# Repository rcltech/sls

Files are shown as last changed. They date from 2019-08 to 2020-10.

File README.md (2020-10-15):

# RC Tech Club Smart Laundry System

This is a mono-repo for the smart laundry system in RC Lee Hall

#### Directory structure

- `ec2`: The AWS EC2 service for the analytics for SLS.
- `hardware`: Code on the ESP8266
- `lambda`: Serverless functions running on the AWS Lambda, communicate with the hardware via internet.
- `sls`: The code for the website.
- `solidworks`: 3D designs for the casing of the sensor modules.

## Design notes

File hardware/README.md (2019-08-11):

# Version 3 Wifi Connection to Wifi.HK via HKU

Test machine: ESP8266

## Setup Instructions

1. Run `pip install -r requirements.txt`
2. Upload `boot.py`, `main.py` and `urequests_mod.py` to the ESP8266
3. Press the reset button to reload the scripts
4. Make sure the sensor circuit is there to read data. Otherwise, value will be 0.

### Watch it send data!

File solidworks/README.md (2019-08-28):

# Solidworks

We 3D-printed, and installed hardware on our laundry machines.

### Instructions
1. Use Solidworks 2018 to open your desired part that is stored in the `Parts/` folder.

2. Save the part as `.STL`.

3. Use Cura or any other 3D-printer software to create `.gcode` file.

4. Print with corresponding 3D printer.

### Our Results
#### Button and LED
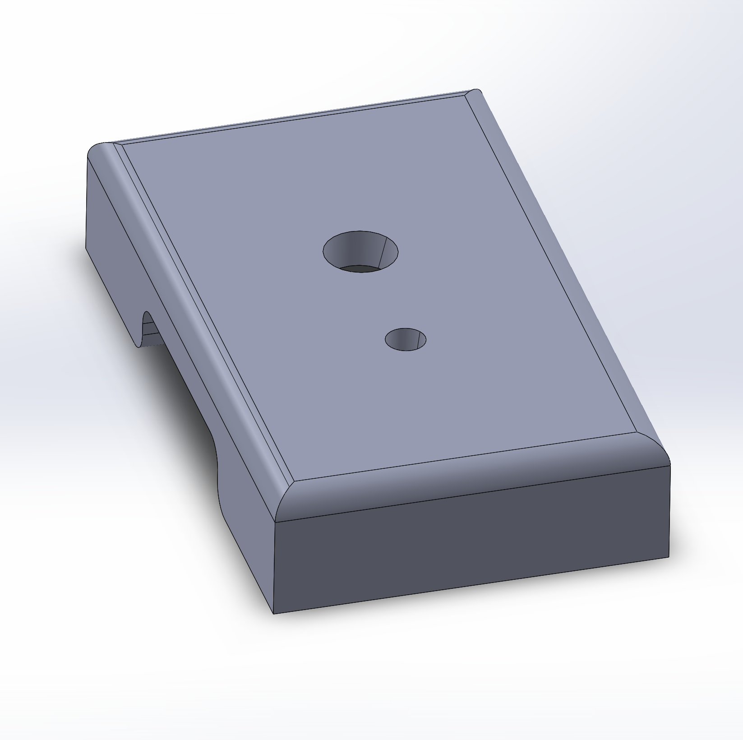
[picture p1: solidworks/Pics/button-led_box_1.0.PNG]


We made our first prototype using a button and an led. For reasons yet unknown, the micropython ESP module was unstable, and it somehow received signals from the buttons without anyone pressing them. Hence, the module kept sending false data to our firebase database, making the entire system very unstable, and unusable.

#### Light sensor
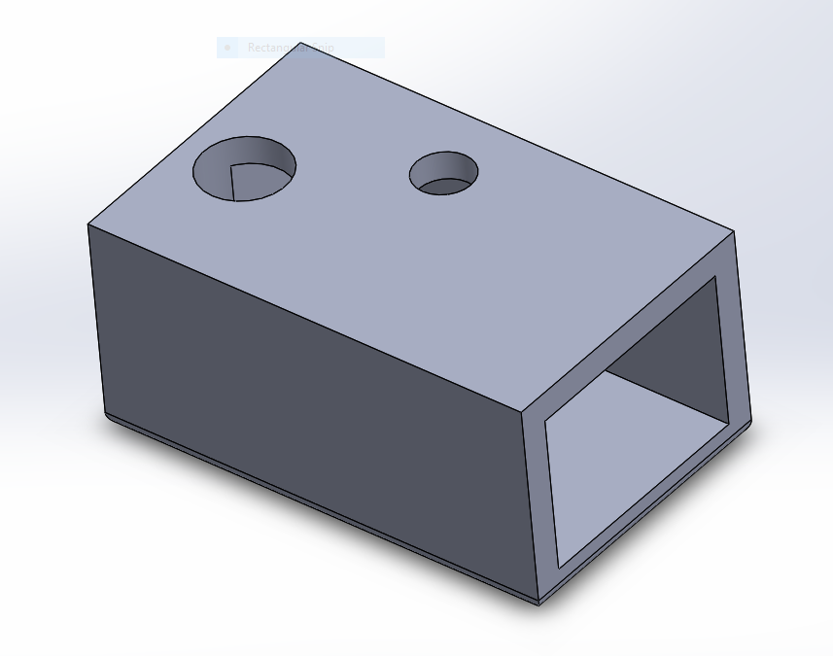
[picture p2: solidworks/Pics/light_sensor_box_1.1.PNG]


Our 2nd prototype implements a digital light sensor that would send on / off signals to the ESP module. As long as we correctly tuned the sensitivity of the sensors, they worked perfectly; so far, we have yet observe any system-disruptive fluctuations.

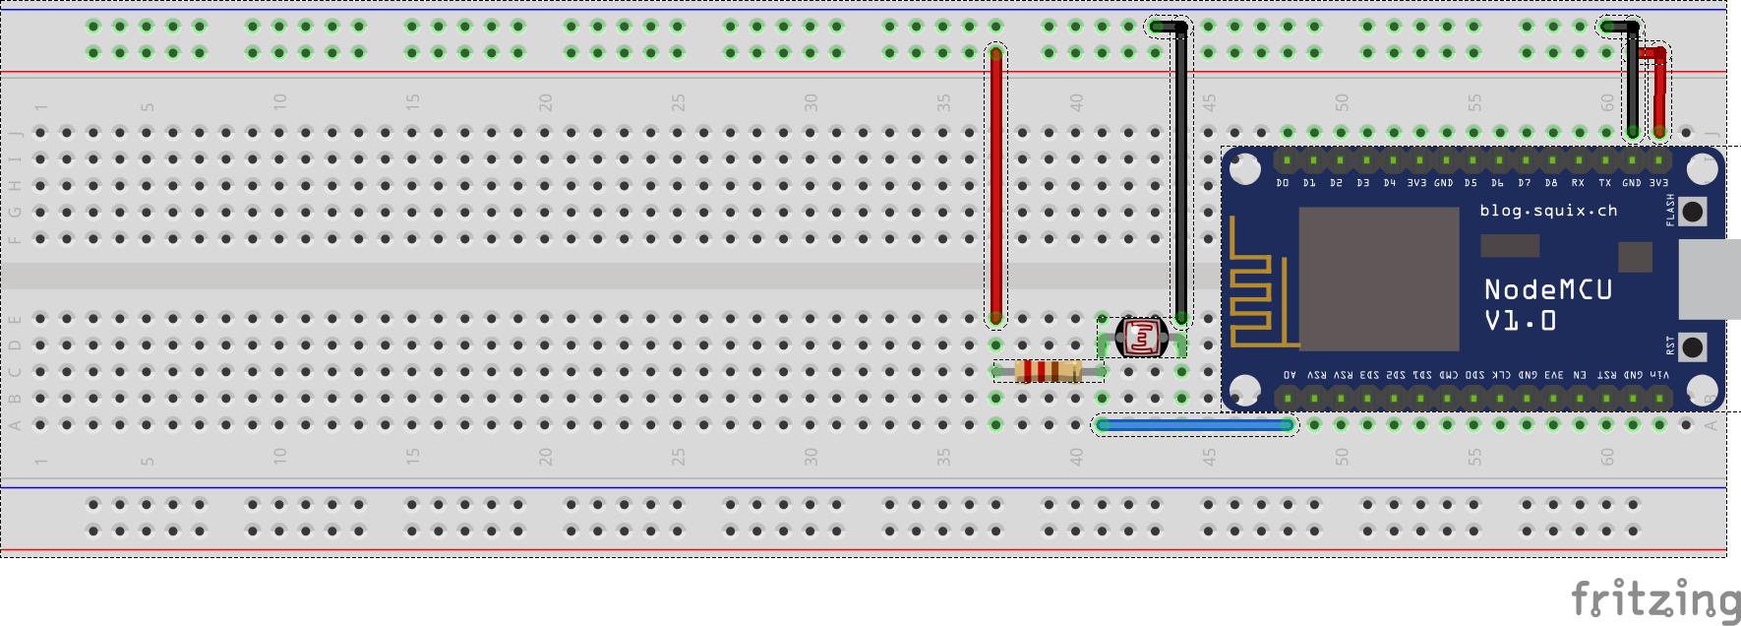
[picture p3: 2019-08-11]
hardware/sls_bb.png

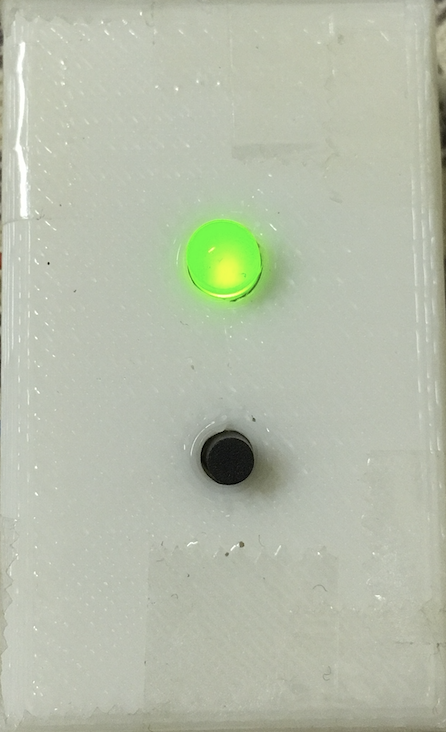
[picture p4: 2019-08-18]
sls/src/images/LED_on.png

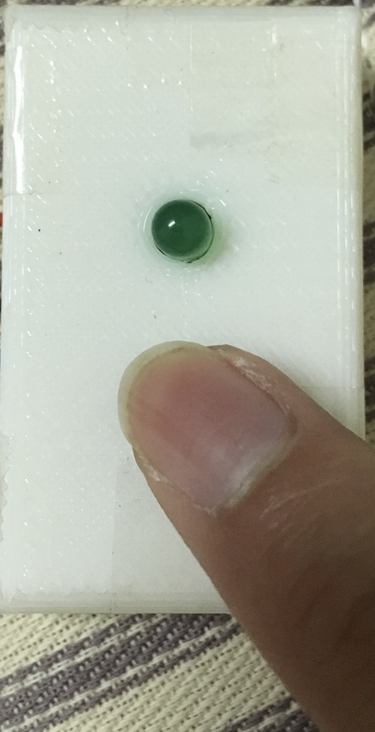
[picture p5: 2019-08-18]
sls/src/images/LED_off_pressed.png

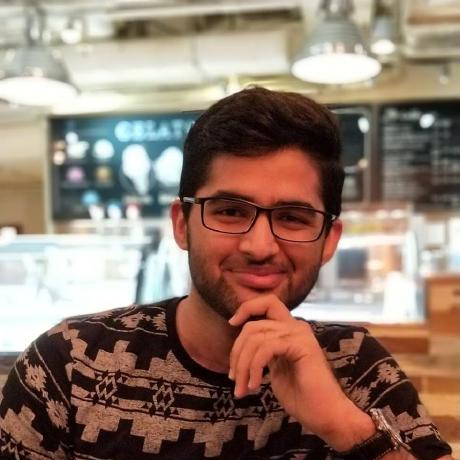
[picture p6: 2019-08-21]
sls/src/images/team-members/waqas.png

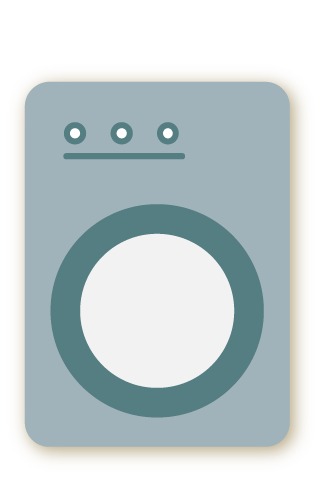
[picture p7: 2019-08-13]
sls/src/images/base.png

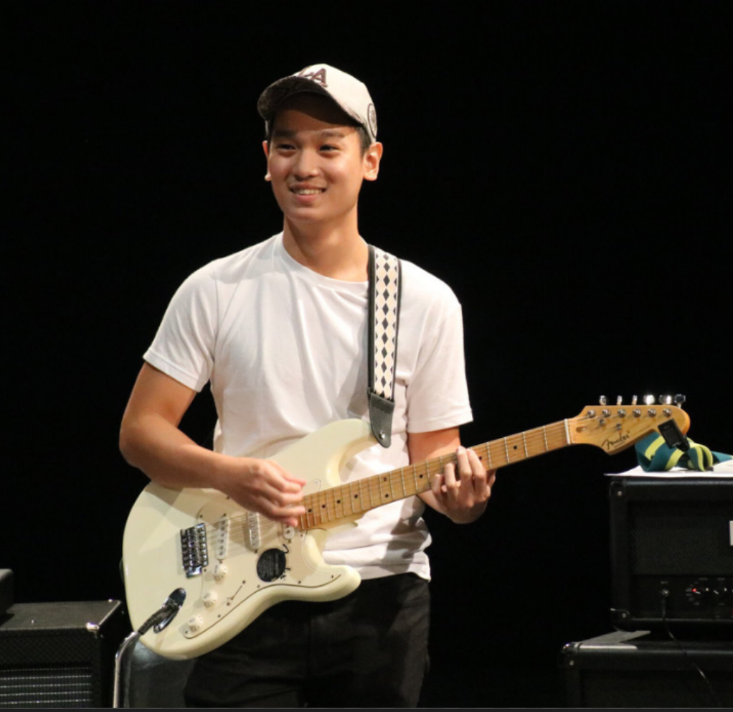
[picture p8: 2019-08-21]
sls/src/images/team-members/welvin.png

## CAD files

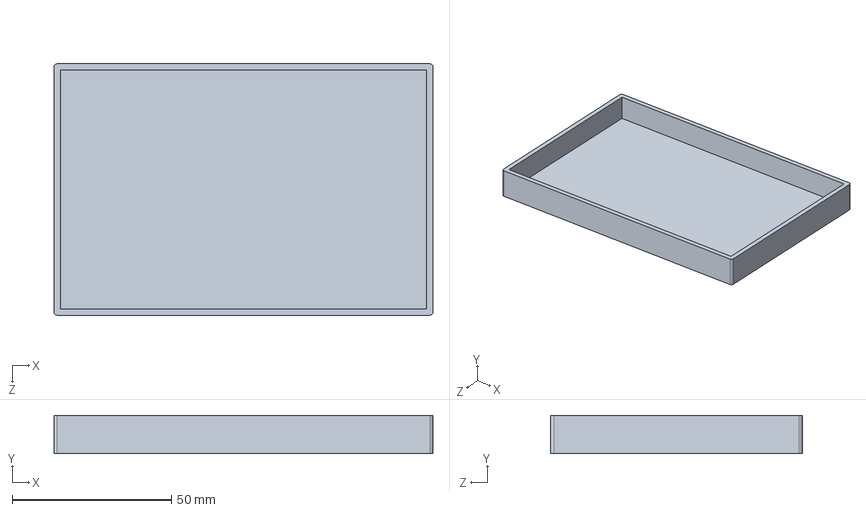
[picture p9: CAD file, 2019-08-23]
solidworks/Parts/main module box 1.0.SLDPRT
119.0 x 12.0 x 79.0 mm

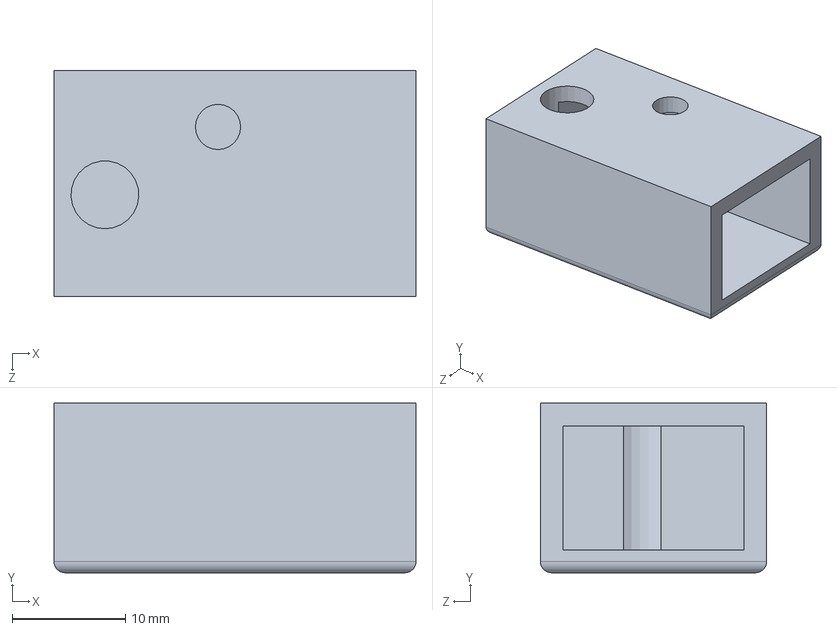
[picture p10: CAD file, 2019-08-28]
solidworks/Parts/light sensor box 1.1.SLDPRT
32.0 x 15.0 x 20.0 mm

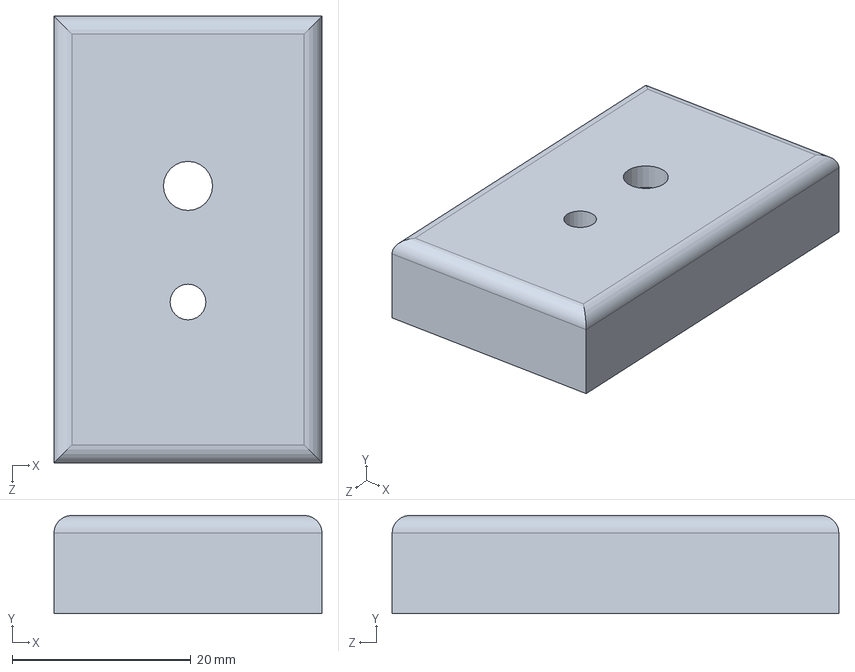
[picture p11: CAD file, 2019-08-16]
solidworks/Parts/button-led box 1.0.SLDPRT
30.0 x 11.0 x 50.0 mm

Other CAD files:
solidworks/Parts/light sensor box 1.0.SLDPRT
solidworks/Parts/button-led box 1.0.STL
solidworks/Parts/light sensor box 1.0.STL
solidworks/Parts/light sensor box 1.1.STL
solidworks/Parts/main module box 1.0.STL

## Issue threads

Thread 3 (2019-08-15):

add countdown timer to washer

98sean98, 2019-08-15:
frontend:
add timer beneath each washer

backend:
micropython - add time when washer button has been pressed, correctly pass data to firebase
react - get time data from firebase, create logic to calculate time remaining

98sean98, 2019-08-15:
> pushed a commit to washer-timer branch, added timer logic to micropython

<sub>[View in Slack](https://rctechclub.slack.com/archives/CFJ8V5ELS/p1565841954001200)</sub>

utkarsh867, 2019-09-23:
we will probably never make this feature.

Closed 2019-09-23.

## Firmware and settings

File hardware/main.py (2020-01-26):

import os
import sys
import uos
import network
import machine
import urequests
import ujson
from machine import ADC
from machine import Pin
from utime import sleep
import gc

p0 = Pin(0, Pin.IN)
p1 = Pin(14, Pin.IN)
p2 = Pin(4, Pin.IN)
p3 = Pin(5, Pin.IN)

p0.value(0)
p1.value(0)
p2.value(0)
p3.value(0)

washer_data = {
    "washer1": 0,
    "washer2": 0,
    "washer3": 0,
    "washer4": 0
}

def read_api_key():
    with open("API_KEY.txt") as f:
        api_key = f.read()
        f.close()
        return api_key

def do_connect():
    sta_if = network.WLAN(network.STA_IF)
    sta_if.active(True)
    print("Attempting to connect")
    if not sta_if.isconnected():
        sta_if.active(True)
        
        #Provide the wifi SSID and password here
        sta_if.connect("Wi-Fi.HK via HKU")
        
        while not sta_if.isconnected():
            pass
    print("connected")

def get_magic():
    # This little mod handles the redirect issue in the urequests
    import urequests_mod
    r = urequests_mod.get('http://msftconnect.com')
    #This is the position where the redirect URL starts. It will be required to initiate the authentication
    url_start = r.text.find('http://')
    #This gives us the position of the magic URL
    magic_start_index = r.text.find('fgtauth') + 8
    magic = r.text[magic_start_index : magic_start_index + 16]
    #The extracted URL
    url = r.text[url_start : magic_start_index + 16]
    r.close()
    return url, magic

"""
    Using the redirect URL and magic value, this function will initiate authentication
    and then complete the authentication, thus connecting to the internet.
"""
def connect_with_magic(url, magic):
    st = "4Tredir=http%3A%2F%2Fmsftconnect.com%2F&magic="+str(magic)+"&username=wifi&password=wifi"
    try:
        #Initiate the authentication by sending GET request to the redirected URL
        print("Logging in to the internet")
        r = urequests.get(url)
        r.close()

        #Complete the authentication by sending the form data to the required URL
        r = urequests.post(url[:url.find("?")], data=st, headers={'Content-Type': 'application/x-www-form-urlencoded'})
        r.close()

    except IndexError:
        print("Already connected to the internet")

    except ValueError:
        print("The device was already logged in. Therefore, there was no URL")

def connect_open_wifi():
    do_connect()
    url, magic = get_magic()
    connect_with_magic(url, magic)

def send_data():
    API_KEY = read_api_key()
    aws_url = 'https://m3q6ssas8g.execute-api.us-east-2.amazonaws.com/default/sls'
    headers = {
        'Accept': 'application/json',
        'Content-Type': 'application/json',
        'x-api-key': API_KEY
    }
    try:
        res = urequests.post(aws_url,json=washer_data,  headers=headers)
        print(res.text)
        res.close()
    except:
        print("There was an exception, trying again")
        connect_open_wifi()
        send_data()

def update_washer_status():
    old_washer_data = washer_data.copy()
    washer_data["washer1"] = p0.value()
    washer_data["washer2"] = p1.value()
    washer_data["washer3"] = p2.value()
    washer_data["washer4"] = p3.value()
    if old_washer_data == washer_data:
        return
    print(washer_data)
    send_data()

def main():     
    connect_open_wifi()
    while(True):
        update_washer_status()
        gc.collect()
        sleep(1)

gc.collect()
main()
gc.collect()

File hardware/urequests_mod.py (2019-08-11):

import usocket

class Response:

    def __init__(self, f):
        self.raw = f
        self.encoding = "utf-8"
        self._cached = None

    def close(self):
        if self.raw:
            self.raw.close()
            self.raw = None
        self._cached = None

    @property
    def content(self):
        if self._cached is None:
            try:
                self._cached = self.raw.read()
            finally:
                self.raw.close()
                self.raw = None
        return self._cached

    @property
    def text(self):
        return str(self.content, self.encoding)

    def json(self):
        import ujson
        return ujson.loads(self.content)


def request(method, url, data=None, json=None, headers={}, stream=None):
    try:
        proto, dummy, host, path = url.split("/", 3)
    except ValueError:
        proto, dummy, host = url.split("/", 2)
        path = ""
    if proto == "http:":
        port = 80
    elif proto == "https:":
        import ussl
        port = 443
    else:
        raise ValueError("Unsupported protocol: " + proto)

    if ":" in host:
        host, port = host.split(":", 1)
        port = int(port)

    ai = usocket.getaddrinfo(host, port, 0, usocket.SOCK_STREAM)
    ai = ai[0]

    s = usocket.socket(ai[0], ai[1], ai[2])
    try:
        s.connect(ai[-1])
        if proto == "https:":
            s = ussl.wrap_socket(s, server_hostname=host)
        s.write(b"%s /%s HTTP/1.0\r\n" % (method, path))
        if not "Host" in headers:
            s.write(b"Host: %s\r\n" % host)
        # Iterate over keys to avoid tuple alloc
        for k in headers:
            s.write(k)
            s.write(b": ")
            s.write(headers[k])
            s.write(b"\r\n")
        if json is not None:
            assert data is None
            import ujson
            data = ujson.dumps(json)
            s.write(b"Content-Type: application/json\r\n")
        if data:
            s.write(b"Content-Length: %d\r\n" % len(data))
        s.write(b"\r\n")
        if data:
            s.write(data)

        l = s.readline()
        l = l.split(None, 2)
        #status = int(l[1])
        print(l)
        status = 200
        reason = ""
        if len(l) > 2:
            reason = l[2].rstrip()
        while True:
            l = s.readline()
            if not l or l == b"\r\n":
                break
            #print(l)
            if l.startswith(b"Transfer-Encoding:"):
                if b"chunked" in l:
                    raise ValueError("Unsupported " + l)
            elif l.startswith(b"Location:") and not 200 <= status <= 299:
                print('redirect')
                #raise NotImplementedError("Redirects not yet supported")
    except OSError:
        s.close()
        raise

    resp = Response(s)
    resp.status_code = status
    resp.reason = reason
    return resp


def head(url, **kw):
    return request("HEAD", url, **kw)

def get(url, **kw):
    return request("GET", url, **kw)

def post(url, **kw):
    return request("POST", url, **kw)

def put(url, **kw):
    return request("PUT", url, **kw)

def patch(url, **kw):
    return request("PATCH", url, **kw)

def delete(url, **kw):
    return request("DELETE", url, **kw)

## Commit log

2019-08-13 add latest code for cloud services
    [sls.fzz]
2019-08-13 change timer and initial data
2019-08-14 optimise firebase request and debounce pin instability
2019-08-15 add solidworks files for hardware
    [button-led box 1.0.SLDPRT, button-led box 1.0.STL]
2019-08-16 update solidworks parts
    [button-led box 1.0.SLDPRT, button-led box 1.0.STL]
2019-08-20 LDR (#13)
    * Add led control for user feedback
    * Change code to LDR
2019-08-23 add solidworks part files (#16)
    [light sensor box 1.0.SLDPRT, light sensor box 1.0.STL, main module box 1.0.SLDPRT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]
2019-08-23 fix css props of about page not displaying properly on ios (#17)
2019-08-28 Documentation (#19)
    [light sensor box 1.1.SLDPRT, light sensor box 1.1.STL]
2020-01-13 Trying to fix issues with periodic stall (#32)
    * Makes minor optimizations
    * fixes issues with the pin value function call
    * closes the request after making it
    [main.py]
